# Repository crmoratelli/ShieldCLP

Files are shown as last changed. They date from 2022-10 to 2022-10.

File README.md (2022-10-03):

# ShieldCLP

  The following project refers to one of the steps in the development of an Open Source PLC with a web interface using Raspberry Pi.
The hardware was developed with the aim of integrating 8 of the microcontroller GPIO's as digital inputs-outputs for the PLC platform, leaving the other ports at the user's disposal.

The shield will allow connection to an N4DBA06 module to support analog inputs and outputs.

The RPI and the N4DBA06 module will be powered through the shield.

The power supply used must have a voltage output of 12Vdc.

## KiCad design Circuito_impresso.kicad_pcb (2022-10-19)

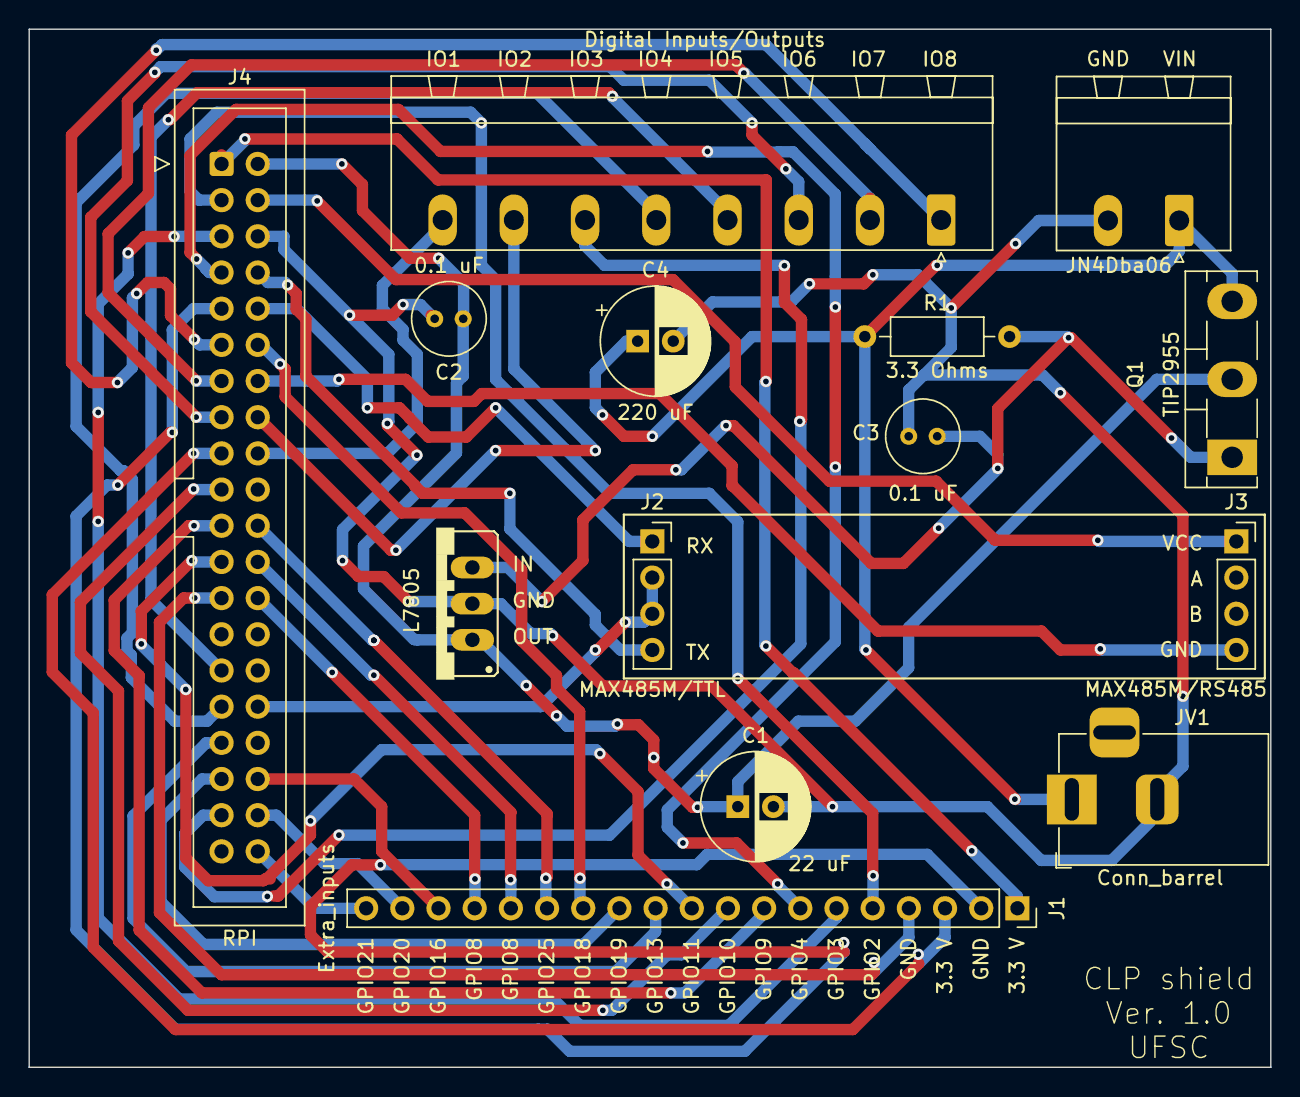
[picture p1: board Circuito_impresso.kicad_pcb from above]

Board: 2 copper layers, 87.2 x 72.9 mm, 14 parts (0 on the bottom side), 36 nets.

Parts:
C1: 22 uF; CP_Radial_D7.5mm_P2.50mm
C2, C3: 0.1 uF; C_Radial_D5.0mm_H5.0mm_P2.00mm
C4: 220 uF; CP_Radial_D7.5mm_P2.50mm
J1: Extra_inputs; PinSocket_1x19_P2.54mm_Vertical
J2: MAX485M/TTL; PinSocket_1x04_P2.54mm_Vertical
J3: MAX485M/RS485; PinSocket_1x04_P2.54mm_Vertical
J4: RPI; IDC-Header_2x20_P2.54mm_Vertical
JIO-1: Digital Inputs/Outputs; PhoenixContact_MSTBA_2,5_8-G_1x08_P5.00mm_Horizontal
JN4Dba06: Conn_01x02; PhoenixContact_MSTBA_2,5_2-G_1x02_P5.00mm_Horizontal
JV1: Conn_barrel; BarrelJack_Horizontal
Q1: TIP2955; TO-218-3_Vertical
R1: 3.3 Ohms; R_Axial_DIN0207_L6.3mm_D2.5mm_P10.16mm_Horizontal
U1: L7805; 78XXS

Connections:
unnamed: C1.1, C2.1, J4.2, Q1.2 (C), U1.3 (IN)
unnamed: C1.2, C2.2, C3.2, C4.2, J4.6, JN4Dba06.2, JV1.2, U1.2 (GND)
unnamed: C3.1, Q1.1 (B), R1.2, U1.1 (OUT)
unnamed: C4.1, JN4Dba06.1, JV1.1, Q1.3 (E), R1.1
unnamed: J1.1, J4.1
unnamed: J1.2, J4.9
unnamed: J1.3, J4.17
unnamed: J1.4, J4.25
unnamed: J1.5, J4.3
unnamed: J1.6, J4.5
unnamed: J1.7, J4.7
unnamed: J1.8, J4.21
unnamed: J1.9, J4.19
unnamed: J1.10, J4.23
unnamed: J1.11, J4.33
unnamed: J1.12, J4.35
unnamed: J1.13, J4.12
unnamed: J1.14, J4.22
unnamed: J1.15, J4.24
unnamed: J1.16, J4.26
unnamed: J1.17, J4.36
unnamed: J1.18, J4.38
unnamed: J1.19, J4.40
unnamed: J2.1, J4.10
unnamed: J2.2, J2.3, J4.32
unnamed: J2.4, J4.8
unnamed: J3.1, J4.4
unnamed: J3.4, J4.14
unnamed: J4.11, JIO-1.1
unnamed: J4.13, JIO-1.2
unnamed: J4.15, JIO-1.3
unnamed: J4.16, JIO-1.7
unnamed: J4.18, JIO-1.8
unnamed: J4.29, JIO-1.4
unnamed: J4.31, JIO-1.5
unnamed: J4.37, JIO-1.6

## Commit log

2022-10-03 Initial Commit
    The schematic is structured and ready. the footprints have been assigned. And the preliminary position of the components on the PCB has been established.
    However, there is a footprint reference to one of the components by a path in the local machine that may not work at first (to be corrected). One of the components on the PCB did not have its connections recognized (to be fixed)
    [Circuito_impresso.kicad_pcb, Circuito_impresso.kicad_sch]
2022-10-04 Finalizes the preliminary design of the PCB
    [Circuito_impresso.kicad_pcb]
2022-10-06 updates to meet requirements; error correction
    the width of the tracks is now 0.8 mm (considering the maximum circuit current of 5 amps, with a maximum increase of 40°C; the position of each terminal of the l7805 in the schematic has been corrected; the position of the L7 so that it heatsink does not collide with the TIP
    The silkscreen must be done
    [Circuito_impresso.kicad_pcb, Circuito_impresso.kicad_sch]
2022-10-10 Error correction; silkscreen insertion.
    The L7805 terminals were inverted on the PCB and have been fixed in this version;
    The identification of some of the terminals was made by inserting the serigraphy of the board
    [Circuito_impresso.kicad_pcb, Circuito_impresso.kicad_sch]
2022-10-19 Adjustments
    Capacitors C2 and C3 have been upgraded from SMD to not polarized through hole; the radius of C1 has been updated; inserted pcb version.
    [Circuito_impresso.kicad_pcb]
2022-12-06 Gerber and drill files submission
    [Circuito_impresso-B_Cu.gbr, Circuito_impresso-B_Mask.gbr, Circuito_impresso-B_Paste.gbr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]
